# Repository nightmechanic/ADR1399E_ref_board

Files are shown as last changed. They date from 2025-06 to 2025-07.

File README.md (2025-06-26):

# ADR1399E Voltage reference circuit

This is a **hobby grade** 10V (well, close to...) voltage refernce based on Analog Devices' ADR1399E reference.
It can be powered with either 5V USB (using a boost switching regulator) , or a 5S Li-Ion pack (or equivalent)

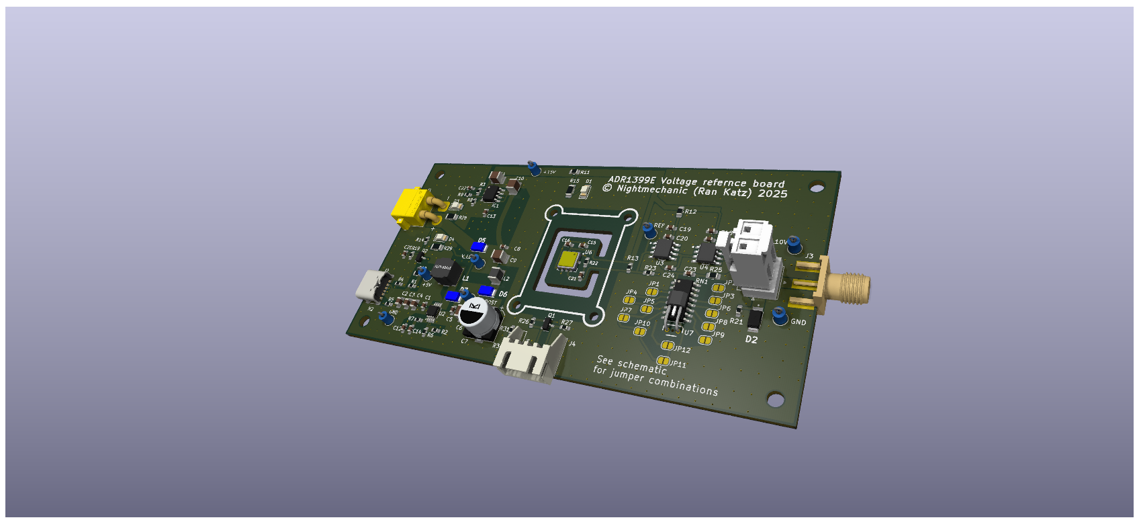
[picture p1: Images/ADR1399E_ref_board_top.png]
Kicad rendering of the board

*(Kicad rendering of the board)*

## Source:
Mostly based on: https://www.eevblog.com/forum/metrology/lm399-based-10-v-reference/ (specifically replies starting from 1300 to about 1343)

## Notes:
Designed in KiCad (9.0)

### Enclosure:
3D printable 2-piece enclosure design in [onshape](https://cad.onshape.com/documents/444727e948f9e5cc4e41eae1/w/781dc2eb3e355c2d7b923edf/e/b0f13c680a3e4fdfcef48c95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)

- Designed to use (4) M3x5x4 ("Voron") threaded inserts and (4) m3x20 screws for securing the base and lid together 
- With 4mm and 2mm Banana socket pairs
- With an (optional) internal refernce covers (identical top and bottom), to, somewhat, thermally isolate the refernce "island" from the rest 

Note that top/lid 3D printing may require supports for the screw head recesses
Printing the internal refernce cover will need supports

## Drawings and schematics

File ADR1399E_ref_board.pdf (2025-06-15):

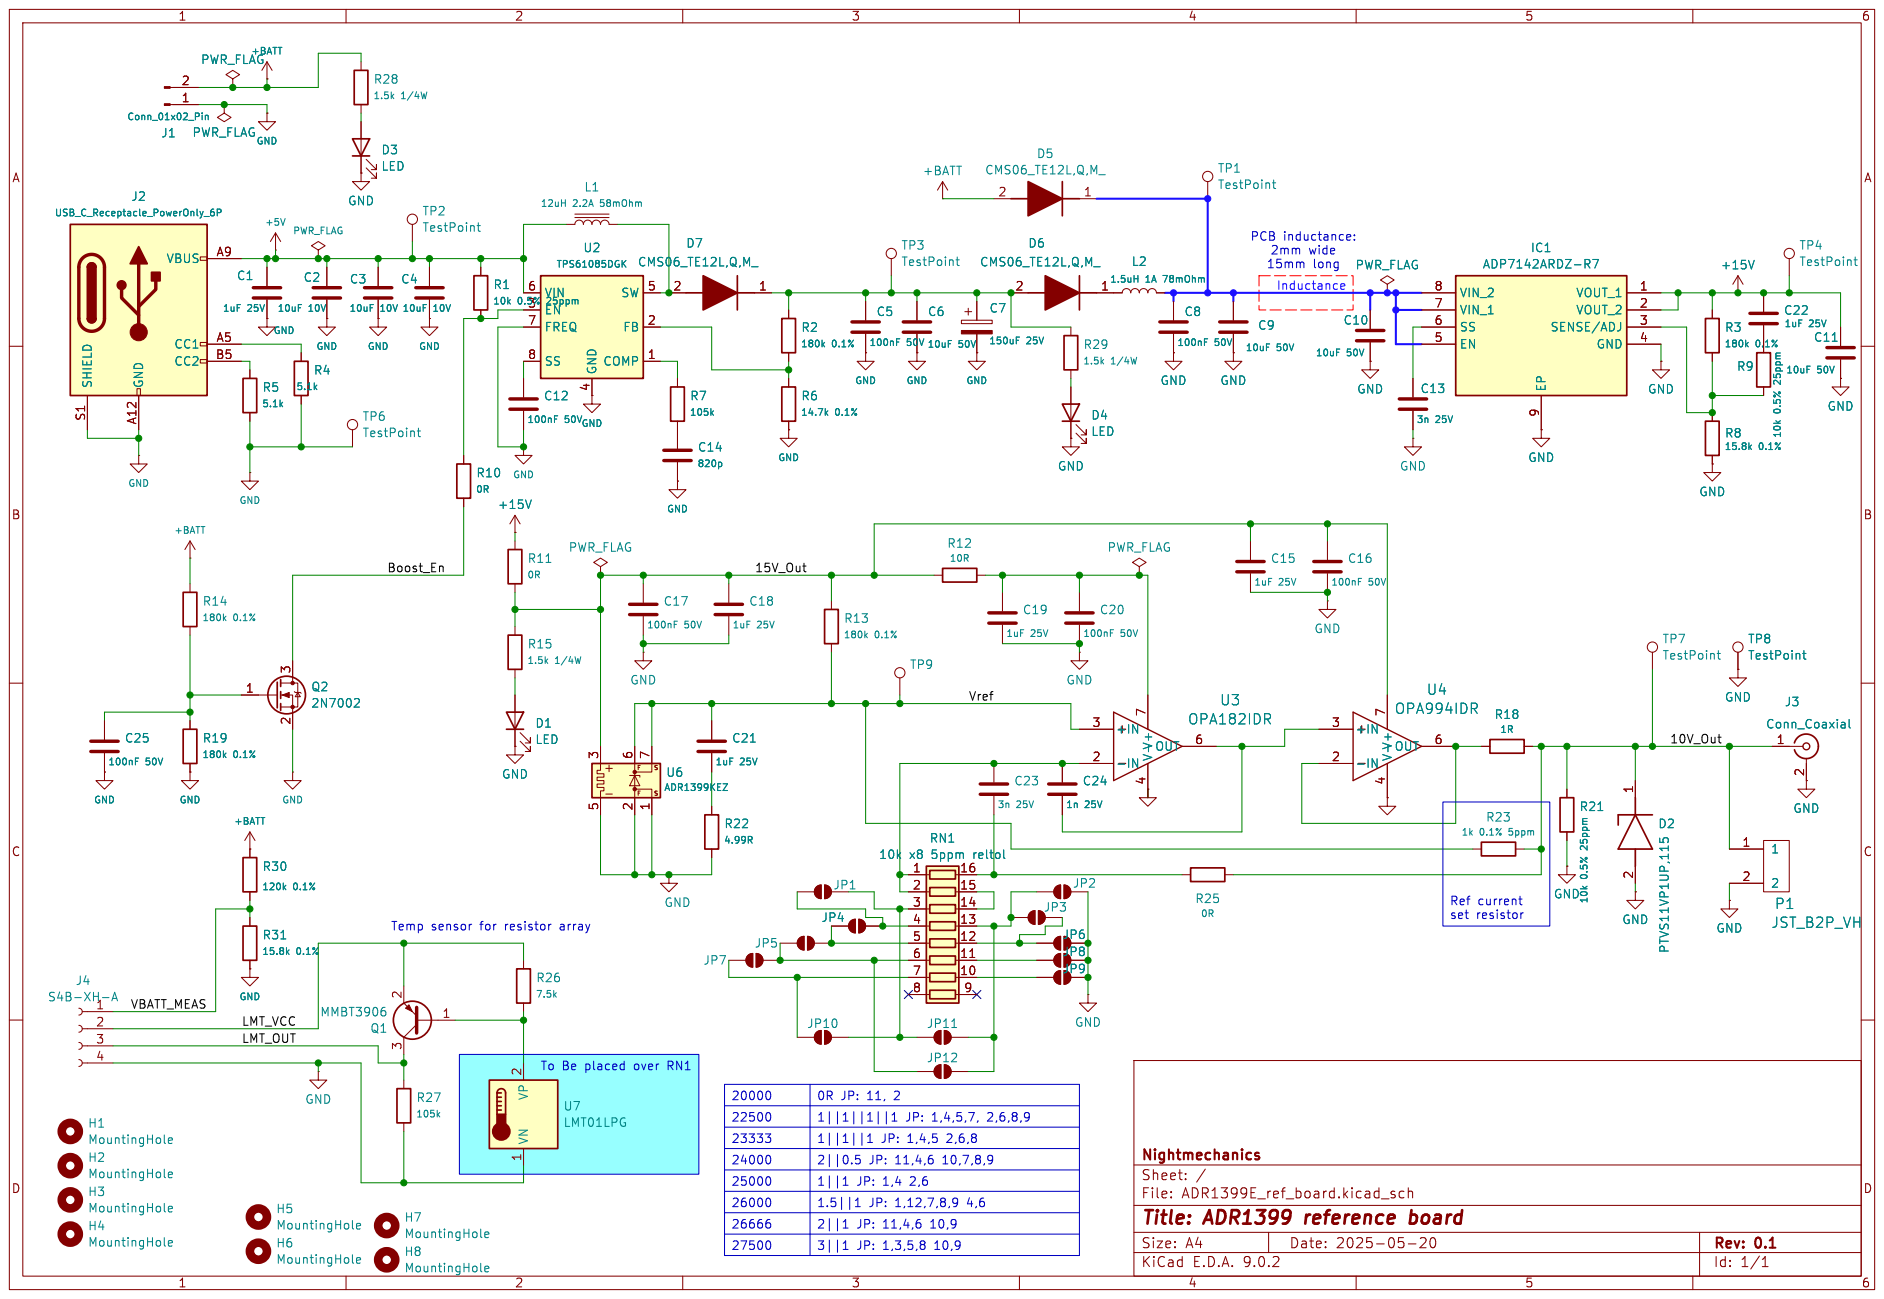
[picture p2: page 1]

4 SW 5 FB 2 COMP 1 GND C12

Id: 1/1 Title: ADR1399 reference board

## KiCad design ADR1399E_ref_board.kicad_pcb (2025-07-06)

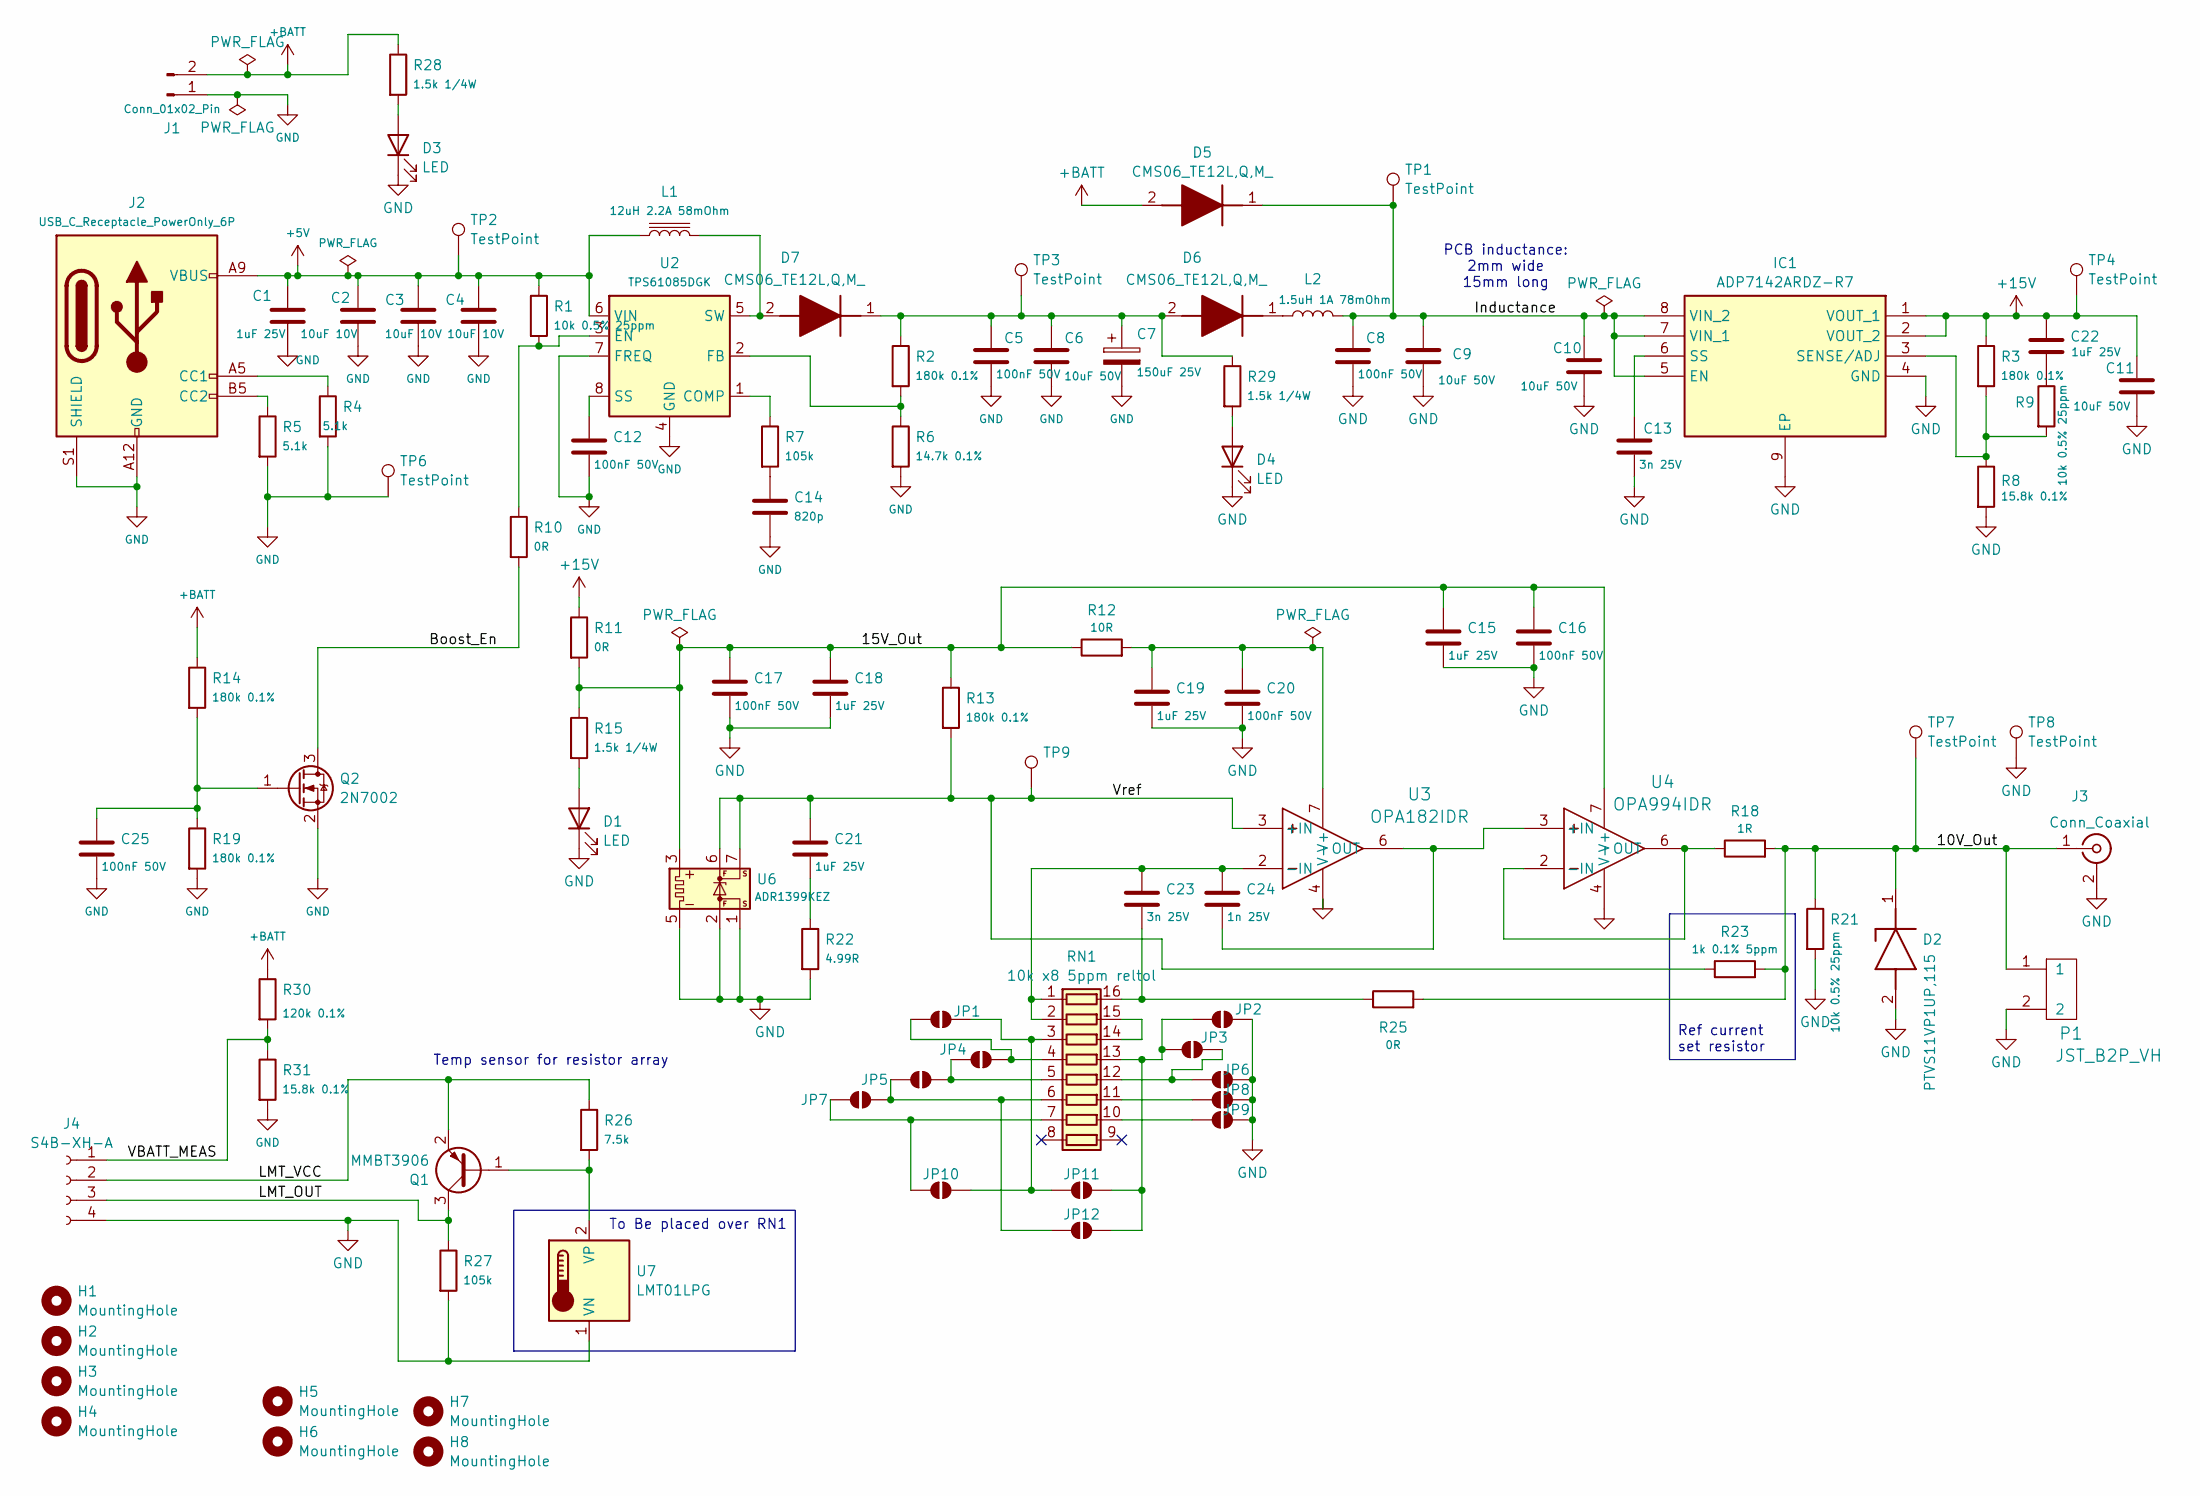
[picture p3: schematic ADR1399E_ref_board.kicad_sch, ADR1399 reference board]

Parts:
C1, C15, C18, C19, C21, C22: 1uF 25V; C_0603_1608Metric_Pad1.08x0.95mm_HandSolder; Manufacturer_Part_Number TMK107ABJ225KA-T
C2, C3, C4: 10uF 10V; C_0805_2012Metric_Pad1.18x1.45mm_HandSolder; Manufacturer_Part_Number CL21A106KPFNNNG
C5, C8, C12, C16, C17, C20, C25: 100nF 50V; C_0603_1608Metric_Pad1.08x0.95mm_HandSolder; Manufacturer_Part_Number CL10B104KB8NNWC
C6, C9, C10, C11: 10uF 50V; C_1210_3225Metric_Pad1.33x2.70mm_HandSolder; Manufacturer_Part_Number CL32A106KBJNNNE
C7: 150uF 25V; CP_Elec_8x6.7; Manufacturer_Part_Number A768KE157M1ELAE029
C13, C23: 3n 25V; C_0603_1608Metric_Pad1.08x0.95mm_HandSolder; Manufacturer_Part_Number GCM1885C1H302JA16D
C14: 820p; C_0603_1608Metric_Pad1.08x0.95mm_HandSolder; Manufacturer_Part_Number CC0603JRNPO9BN821
C24: 1n 25V; C_0603_1608Metric_Pad1.08x0.95mm_HandSolder; Manufacturer_Part_Number C0603C102J5GAC7411
D1, D3, D4: LED; LED_1206_3216Metric_Pad1.42x1.75mm_HandSolder; Manufacturer_Part_Number IN-S126ATA
D2: PTVS11VP1UP,115; PMEG3050EP115; Mouser Part Number 771-PTVS11VP1UP115
D5, D6, D7: CMS06_TE12L,Q,M_; SODFL4724X108N; Mouser Part Number 757-CMS06TE12L,Q,M
H1, H2, H3, H4: MountingHole; MountingHole_3.2mm_M3_ISO7380
H5, H6, H7, H8: MountingHole; MountingHole_2.2mm_M2
IC1: ADP7142ARDZ-R7; SOIC-8-1EP_3.9x4.9mm_P1.27mm_EP2.29x3mm_ThermalVias; Mouser Part Number 584-ADP7118ARDZ-R7
J1: Conn_01x02_Pin; AMASS_XT30PW-M_1x02_P2.50mm_Horizontal
J2: USB_C_Receptacle_PowerOnly_6P; USB_C_Receptacle_GCT_USB4125-xx-x-0190_6P_TopMnt_Horizontal; Manufacturer_Part_Number USB4125-GF-A-0190
J3: Conn_Coaxial; SMA_Molex_73251-1153_EdgeMount_Horizontal; Manufacturer_Part_Number 73251-1150
J4: S4B-XH-A; JST_XH_S4B-XH-A-1_1x04_P2.50mm_Horizontal; Manufacturer_Part_Number S4B-XH-A-GU
JP1, JP2, JP3, JP4, JP5, JP6, JP7, JP8, JP9, JP10, JP11, JP12: SolderJumper_2_Open; SolderJumper-2_P1.3mm_Open_RoundedPad1.0x1.5mm
L1: 12uH 2.2A 58mOhm; ASPI-6045S; Manufacturer_Part_Number ASPI-6045S-120M-T
L2: 1.5uH 1A 78mOhm; L_1210_3225Metric_Pad1.42x2.65mm_HandSolder; Manufacturer_Part_Number LBC3225T1R5MR
P1: JST_B2P_VH; JST_VH_B2P-VH_1x02_P3.96mm_Vertical; Manufacturer_Part_Number B2P-VH-GU
Q1: MMBT3906; SOT-23; Manufacturer_Part_Number MMBT3906LT1G
Q2: 2N7002; SOT-23
R1, R9, R21: 10k 0.5% 25ppm; R_0603_1608Metric_Pad0.98x0.95mm_HandSolder; Manufacturer_Part_Number MCT06030D1002DP500
R2, R3, R13, R14, R19: 180k 0.1%; R_0603_1608Metric_Pad0.98x0.95mm_HandSolder; Manufacturer_Part_Number ERA-3AEB184V
R4, R5: 5.1k; R_0603_1608Metric_Pad0.98x0.95mm_HandSolder; Manufacturer_Part_Number RG1608P-512-D-T5
R6: 14.7k 0.1%; R_0603_1608Metric_Pad0.98x0.95mm_HandSolder; Manufacturer_Part_Number ERA-3AEB1782V
R7, R27: 105k; R_0603_1608Metric_Pad0.98x0.95mm_HandSolder; Manufacturer_Part_Number RT0603DRD07105KL
R8: 15.8k 0.1%; R_0603_1608Metric_Pad0.98x0.95mm_HandSolder; Manufacturer_Part_Number RG1608P-512-D-T5
R10, R11, R25: 0R; R_0805_2012Metric_Pad1.20x1.40mm_HandSolder; Manufacturer_Part_Number MCU0805MZ0000ZP500
R12: 10R; R_0805_2012Metric_Pad1.20x1.40mm_HandSolder; Manufacturer_Part_Number RR1220Q-100-D
R15, R28, R29: 1.5k 1/4W; R_1206_3216Metric_Pad1.30x1.75mm_HandSolder; Manufacturer_Part_Number RNCP1206FTD1K50
R18: 1R; R_0805_2012Metric_Pad1.20x1.40mm_HandSolder; Manufacturer_Part_Number RT0805BRD071RL
R22: 4.99R; R_0603_1608Metric_Pad0.98x0.95mm_HandSolder; Manufacturer_Part_Number RT0603DRE074R99L
R23: 1k 0.1% 5ppm; R_0603_1608Metric_Pad0.98x0.95mm_HandSolder; Manufacturer_Part_Number PCF0603-13-1K0BT1
R26: 7.5k; R_0603_1608Metric_Pad0.98x0.95mm_HandSolder; Manufacturer_Part_Number RT0603FRE077K5L
R30: 120k 0.1%; R_0603_1608Metric_Pad0.98x0.95mm_HandSolder; Manufacturer_Part_Number ERA-3AEB124V
R31: 15.8k 0.1%; R_0603_1608Metric_Pad0.98x0.95mm_HandSolder; Manufacturer_Part_Number ERA-3AEB1782V
RN1: 10k x8 5ppm reltol; SO-16_3.9x9.9mm_P1.27mm; Manufacturer_Part_Number NOMCT16031002AT1
TP1, TP2, TP3, TP4, TP6, TP7, TP8, TP9: TestPoint; TestPoint_Loop_D1.80mm_Drill1.0mm_Beaded
U2: TPS61085DGK; VSSOP-8_3x3mm_P0.65mm; Manufacturer_Part_Number TPS61085DGKR
U3: OPA182IDR; D0008A-IPC_A; Manufacturer_Part_Number OPA182IDR
U4: OPA994IDR; D0008A-IPC_A; Manufacturer_Part_Number OPA994IDR
U6: ADR1399KEZ; Analog_LCC-8_5x5mm_P1.27mm; Manufacturer_Part_Number ADR1399KEZ
U7: LMT01LPG; LMT01LPG_LPG0002A; Manufacturer_Part_Number LMT01LPGM

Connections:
+5V: C1.1, C2.1, C3.1, C4.1, J2.A9 (VBUS), J2.B9 (VBUS), L1.1, R1.1, TP2.1, U2.6 (VIN)
+15V: C11.1, C22.1, IC1.1 (VOUT_1), IC1.2 (VOUT_2), R3.1, R11.1, TP4.1
+BATT: D5.2 (A), J1.2, R14.1, R28.1, R30.1
/10V_Out: D2.1 (K), J3.1 (In), P1.1, R18.2, R21.1, R23.2, R25.2, TP7.1
/15V_Out: C15.1, C16.1, C17.1, C18.1, R11.2, R12.1, R13.1, R15.1, U4.7 (V+), U6.3 (HEATER+)
/Boost_En: Q2.3 (D), R10.2
/Inductance: C8.1, C9.1, C10.1, D5.1 (K), IC1.5 (EN), IC1.7 (VIN_1), IC1.8 (VIN_2), L2.2, TP1.1
/LMT_OUT: J4.3, Q1.3 (C), R27.1
/LMT_VCC: J4.2, Q1.2 (E), R26.1
/VBATT_MEAS: J4.1, R30.2, R31.1
/Vref: C21.1, R13.2, R23.1, TP9.1, U3.3 (+IN), U6.6 (+REFF), U6.7 (+REFS)
GND: C1.2, C2.2, C3.2, C4.2, C5.2, C6.2, C7.2, C8.2, C9.2, C10.2, C11.2, C12.2, C13.2, C14.2, C15.2, C16.2, C17.2, C18.2, C19.2, C20.2, C25.2, D1.1 (K), D2.2 (A), D3.1 (K), D4.1 (K), IC1.4 (GND), IC1.9 (EP), J1.1, J2.A12 (GND), J2.B12 (GND), J2.S1 (SHIELD), J3.2 (Ext), J4.4, JP2.2 (B), JP6.2 (B), JP8.2 (B), JP9.2 (B), P1.2, Q2.2 (S), R4.2, R5.2, R6.2, R8.2, R19.2, R21.2, R22.2, R27.2, R31.2, TP6.1, TP8.1, U2.4 (GND), U2.7 (FREQ), U3.4 (V-), U4.4 (V-), U6.1 (-REFS), U6.2 (-REFF), U6.5 (HEATER-), U7.1 (VN)
unnamed: C14.1, R7.2
unnamed: C21.2, R22.1
unnamed: C22.2, R9.1
unnamed: D1.2 (A), R15.2
unnamed: D3.2 (A), R28.2
unnamed: D4.2 (A), R29.2
unnamed: C5.1, C6.1, C7.1, D6.2 (A), D7.1 (K), R2.1, R29.1, TP3.1
unnamed: D6.1 (K), L2.1
unnamed: D7.2 (A), L1.2, U2.5 (SW)
unnamed: IC1.3 (SENSE/ADJ), R3.2, R8.1, R9.2
unnamed: C13.1, IC1.6 (SS)
unnamed: J2.A5 (CC1), R4.1
unnamed: J2.B5 (CC2), R5.1
unnamed: JP1.1 (A), JP4.2 (B), RN1.4 (R4.1)
unnamed: JP1.2 (B), JP10.2 (B), JP11.1 (A), RN1.3 (R3.1)
unnamed: JP3.2 (B), JP6.1 (A), RN1.12 (R5.2)
unnamed: JP4.1 (A), JP5.2 (B), RN1.5 (R5.1)
unnamed: JP8.1 (A), RN1.11 (R6.2)
unnamed: JP9.1 (A), RN1.10 (R7.2)
unnamed: JP7.1 (A), JP10.1 (A), RN1.7 (R7.1)
unnamed: JP2.1 (A), JP3.1 (A), JP11.2 (B), JP12.2 (B), RN1.13 (R4.2)
unnamed: JP5.1 (A), JP7.2 (B), JP12.1 (A), RN1.6 (R6.1)
unnamed: Q1.1 (B), R26.2, U7.2 (VP)
unnamed: C25.1, Q2.1 (G), R14.2, R19.1
unnamed: C23.1, C24.1, RN1.1 (R1.1), RN1.2 (R2.1), U3.2 (-IN)
unnamed: C23.2, R25.1, RN1.16 (R1.2)
unnamed: RN1.14 (R3.2), RN1.15 (R2.2)
unnamed: R7.1, U2.1 (COMP)
unnamed: R1.2, R10.1, U2.3 (EN)
unnamed: R2.2, R6.1, U2.2 (FB)
unnamed: C12.1, U2.8 (SS)
unnamed: C24.2, U3.6 (OUT), U4.3 (+IN)
unnamed: C19.1, C20.1, R12.2, U3.7 (V+)
unnamed: R18.1, U4.2 (-IN), U4.6 (OUT)

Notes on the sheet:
PCB inductance: 2mm wide 15mm long
Temp sensor for resistor array
Ref current set resistor
To Be placed over RN1

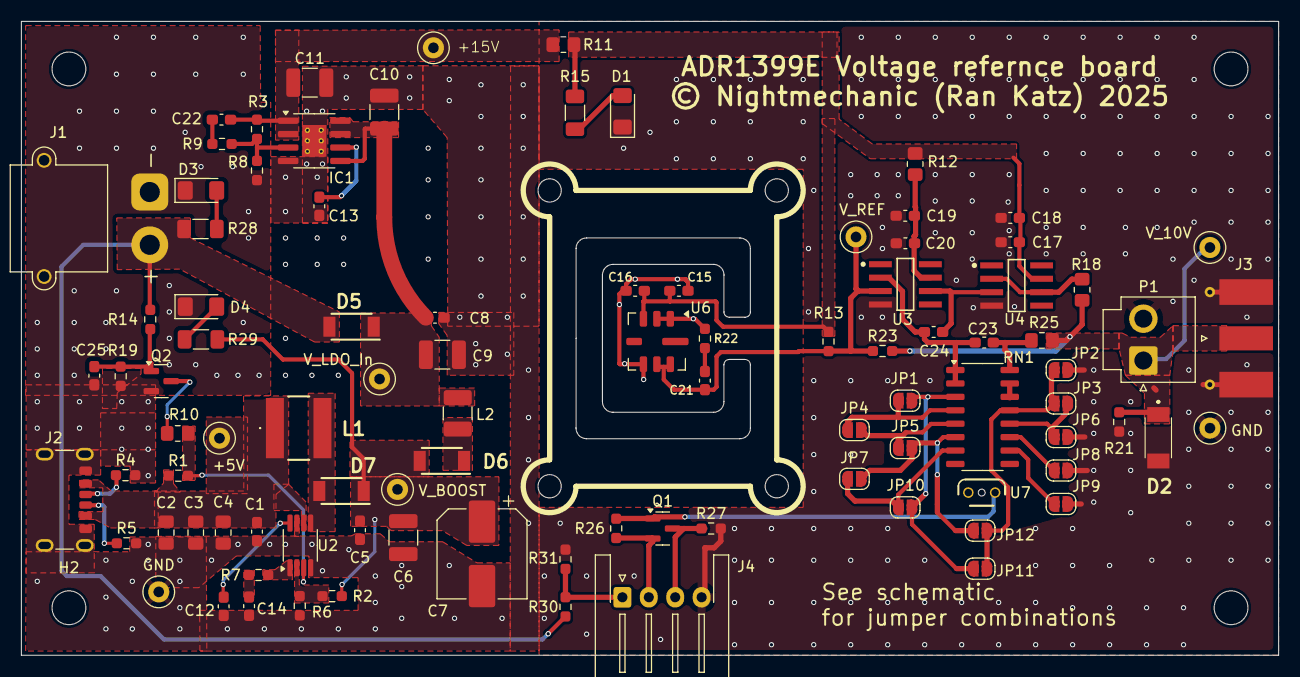
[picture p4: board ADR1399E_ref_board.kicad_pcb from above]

Board: 4 copper layers, 119.0 x 60.0 mm, 103 parts (0 on the bottom side), 46 nets.

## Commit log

2025-05-19 moving forward
    [ADR1399E_ref_board.kicad_pcb, ADR1399E_ref_board.kicad_sch]
2025-05-25 getting closer
    [ADR1399E_ref_board.kicad_pcb, ADR1399E_ref_board.kicad_sch]
2025-05-25 complete schematics?
    [ADR1399E_ref_board.kicad_sch]
2025-06-04 buffered output, temp sensor, resistor network
    [ADR1399E_ref_board.kicad_sch]
2025-06-04 added schematic pdf
    [ADR1399E_ref_board.kicad_sch]
2025-06-08 Final BOM (?)
    [ADR1399E_ref_board.kicad_sch]
2025-06-08 started layout
    [ADR1399E_ref_board.kicad_pcb]
2025-06-09 more layout prep
    [ADR1399E_ref_board.kicad_pcb]
2025-06-09 3d model and footprint updates
    [ADR1399E_ref_board.kicad_pcb, ADR1399E_ref_board.kicad_sch]
2025-06-09 more 3d model updates
    [ADR1399E_ref_board.kicad_pcb]
2025-06-09 more layout
    [ADR1399E_ref_board.kicad_pcb, ADR1399E_ref_board.kicad_sch]
2025-06-10 widen USB connector slots
    [ADR1399E_ref_board.kicad_pcb]
2025-06-10 maybe power done
    [ADR1399E_ref_board.kicad_pcb]
2025-06-11 Reference Island formed!
    [ADR1399E_ref_board.kicad_pcb, ADR1399E_ref_board.kicad_sch]
2025-06-11 initial amp placement
    initial amp placement
    Added Vbatt divider
    [ADR1399E_ref_board.kicad_pcb, ADR1399E_ref_board.kicad_sch]
2025-06-11 more cleanup
    [ADR1399E_ref_board.kicad_pcb, ADR1399E_ref_board.kicad_sch]
2025-06-12 copper balancing
    [ADR1399E_ref_board.kicad_pcb]
2025-06-12 moved from lt3042 to adp7118
    [ADR1399E_ref_board.kicad_sch]
2025-06-12 updated PCB to adp7118/42
    [ADR1399E_ref_board.kicad_pcb]
2025-06-12 changed to 15V, adp7142
    [ADR1399E_ref_board.kicad_pcb, ADR1399E_ref_board.kicad_sch]
2025-06-15 Replaced Boost enable comparator with N-MOS
    also changed Vbatt divider resistor value
    [ADR1399E_ref_board.kicad_pcb, ADR1399E_ref_board.kicad_sch]
2025-06-18 bended temp sensor model
    [ADR1399E_ref_board.kicad_pcb]
2025-06-19 moved VH connector to center
    avoid collision with Banana sockets (in case)
    [ADR1399E_ref_board.kicad_pcb]
2025-06-25 really centered the VH connector
    And added VH housing 3d model
    [ADR1399E_ref_board.kicad_pcb]
2025-06-26 moved USB connector a bit
    better enclosure fit
    [ADR1399E_ref_board.kicad_pcb]
2025-07-06 Updated sllkscreen (logo etc.)
    [ADR1399E_ref_board.kicad_pcb]

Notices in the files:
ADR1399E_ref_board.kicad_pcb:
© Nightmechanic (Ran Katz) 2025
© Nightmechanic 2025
